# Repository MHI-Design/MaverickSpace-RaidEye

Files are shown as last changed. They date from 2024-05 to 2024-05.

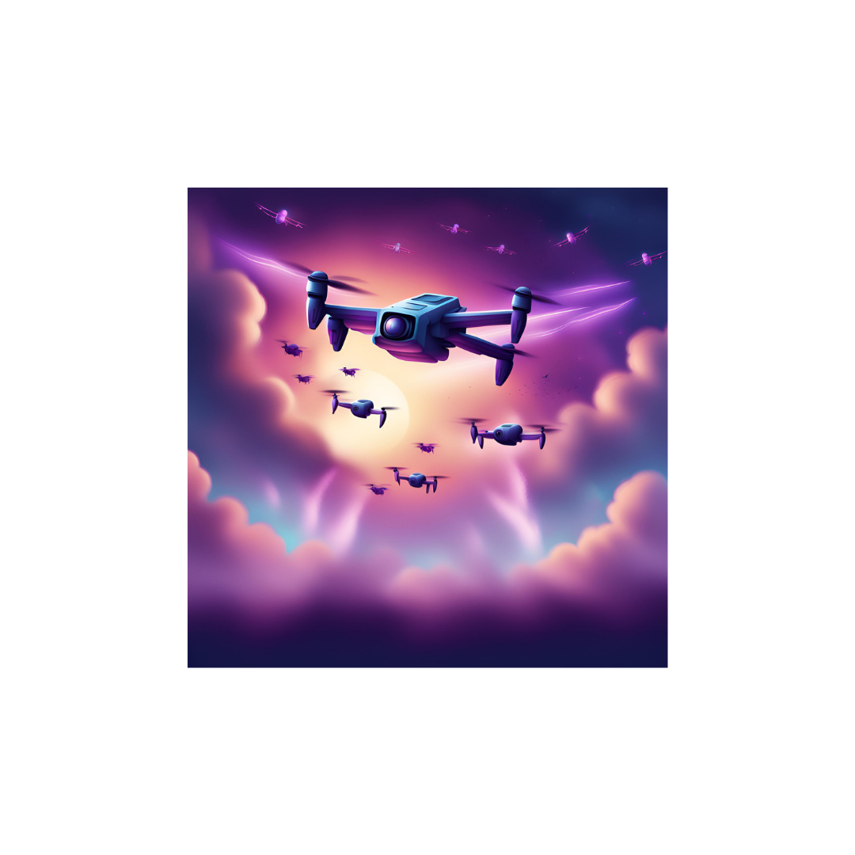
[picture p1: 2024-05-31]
Mobil Uygulama Yazılımı/uygulama/assets/images/Adsız tasarım.png

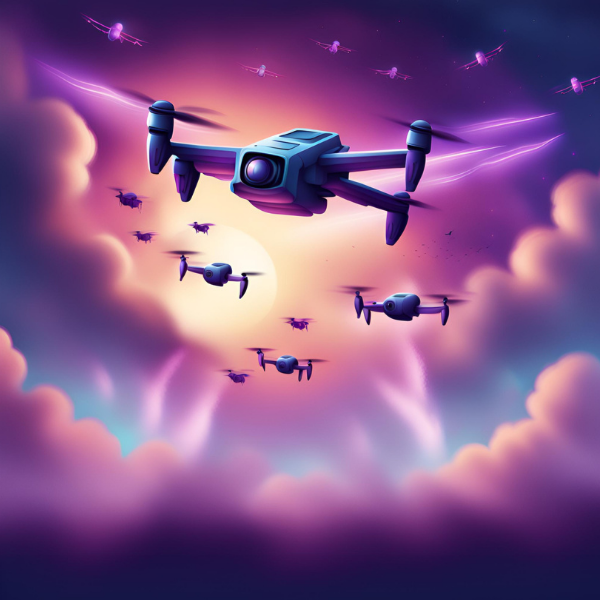
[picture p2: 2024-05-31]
Mobil Uygulama Yazılımı/uygulama/assets/images/drone.png

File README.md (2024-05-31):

# Raid Eye - Kamikaze İHA Sinyal Tespit ve İkaz Sistemi

## Proje Tanıtımı
Raid Eye projesi, askerlerimizin güvenliğini tehdit eden kamikaze insansız hava araçlarına (İHA) karşı önlem almak için geliştirilmiştir. Projenin temel amacı şu şekilde özetlenebilir:

Kamikaze İHA'ların 5.8 GHz frekansındaki kontrol ve görüntü aktarım sinyallerini tespit etmek
Bu sinyallerin kuvvetini ölçerek yaklaşan tehlikeyi belirlemek
Tespit edilen tehlikeyi sesli uyarı sistemiyle askerlerimize bildirerek önlem alınmasını sağlamak
Böylece, FPV (First Person View) teknolojisi kullanan kamikaze İHA'ların neden olabileceği kayıpların önüne geçilmesi hedeflenmektedir. Maverick Space ekibi, askeri operasyonlarda
bilinmeyen alanlarda karşılaşılabilecek bu tehdidin önlenmesi için Raid Eye projesini geliştirmiştir.

Kısaca, Raid Eye sistemi, 5.8 GHz frekansındaki sinyalleri algılayarak yaklaşan kamikaze İHA'lara karşı askerlerimizi önceden uyaran bir güvenlik çözümüdür.

Donanım Tasarım Görselleri
3d_2

https://github.com/MHI-Embedded-Dev/MaverickSpace-RaidEye/assets/132624287/f9e3f8c7-b252-42bd-ad0d-98eca6fa7957

animasyon_gorsel2

Sistem blok şeması
Başlıksız Diyagram drawio

Gömülü yazılımın çalıtığını proteus ile simüle edilmiştir.

simülasyon_jpg

## Dosya Yapısı
- **Donanım Tasarım/**: PCB tasarım dosyaları, montaj animasyon videosu ve 3D kutu tasarımı.
- **Gömülü Yazılımı/**: Gömülü yazılım kaynak kodları ve dokümantasyonu.
- **Mobil Uygulama Yazılımı/**: Arayüz yazılımı kaynak kodları ve dokümantasyonu.
- **Rapor ve Sunum/**: Proje raporları ve sunumları.

## Kurulum ve Çalıştırma
### Donanım
- PCB dosyalarını `Donanım Tasarımı\hecatlon_raid_eye\gerber_to_order` klasöründen indirin ve bir PCB üreticisine gönderin.
-Raid Eye kartının dizgisi için gerekli olan dosyaları ‘Donanım Tasarımı\hecatlon_raid_eye\bom’ malzemeler sipariş verilerek dizgi işlemi yapılabilir.
- Montaj talimatlarına `Donanım Tasarımı\hecatlon_raid_eye\bom` dosyasından ulaşabilirsiniz. Dizgi işleminde süreci hızlandırma bir eklenti ile hazırlanmıştır.



### Gömülü Yazılım
- Gömülü yazılım kaynak kodlarını iki kısıma ayrılmaktadır. ESP32 ve STM32 tarafı olmak üzere STM32 kodları `Gömülü Yazılımı\STM32F446RE\Hecaton_Raid_EYE\Core\Src\main.c` algoritma işleyişi ve sensörleri okuma işlemini yapar. klasöründen bulun.
-ESP32 kodları ‘Gömülü Yazılımı\ESP32-WROOM\Raid_Eye_ESP32’ bluetooth ile mobil uygulamaya bağlantısı gerçekleştirilir. Yapılan sinyal ölçümleri ve ikaz durumu mobil uygulamaya iletilmektedir.
- Yazılımın nasıl yükleneceği ve çalıştırılacağı ile ilgili bilgi için 
ESP32 kodu ve çalıştırma readme dosyası`C:\Github\MaverickSpace-RaidEye\Gömülü Yazılımı\ESP32-WROOM\Raid_Eye_ESP32\readme.txt` dosyasına bakın.
STM32  kodu ve çalıştırma readme dosyası` Gömülü Yazılımı\STM32F446RE\Hecaton_Raid_EYE` dosyasına bakın.

### Arayüz Yazılımı
- Arayüz yazılımı kaynak kodlarını ` Mobil Uygulama Yazılımı\uygulama\src\main.c` klasöründen bulun.
- Mobil Uygulama kodu ve çalıştırma readme dosyası ‘Mobil Uygulama Yazılımı\uygulama\README.txt’ dosyasına bakın.

## İletişim
Muhammed Hüseyin İSMAİL -> mhi.hsynn@gmail.com

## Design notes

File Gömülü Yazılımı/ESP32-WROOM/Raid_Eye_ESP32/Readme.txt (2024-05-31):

//SD CARD
SPI.h
SD.h

//BLUETOOTH BLE
BLEDevice.h
BLEServer.h
BLEUtils.h
BLE2902.h

//I2C
Wire.h

Bu kütühaneleri indirilmesi gereklidir.

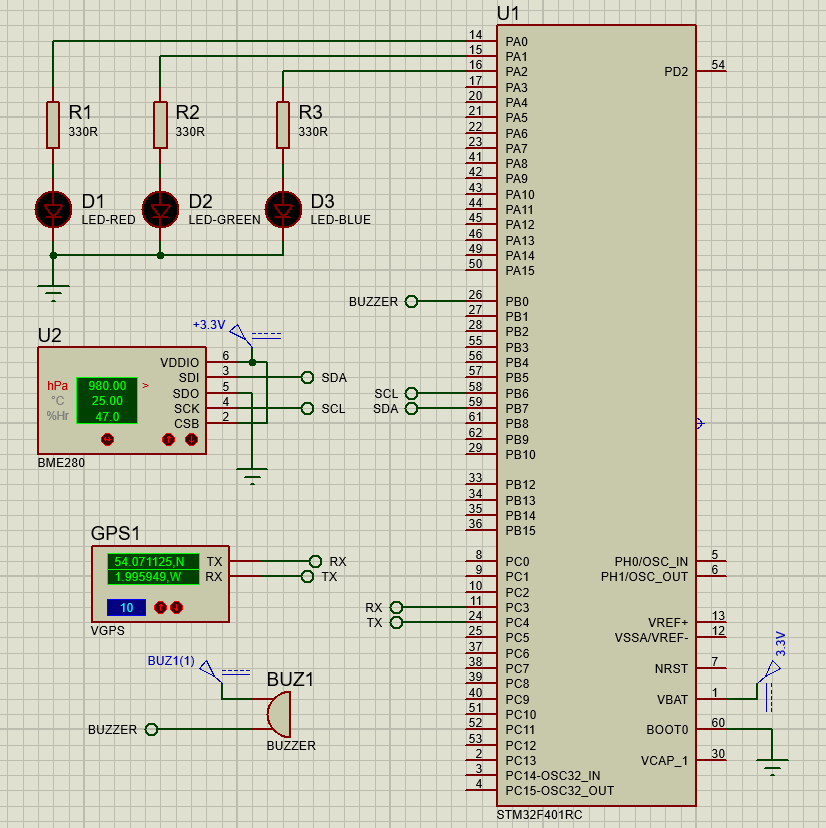
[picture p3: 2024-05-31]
Gömülü Yazılımı/Simülasyon/simülasyon_jpg.png

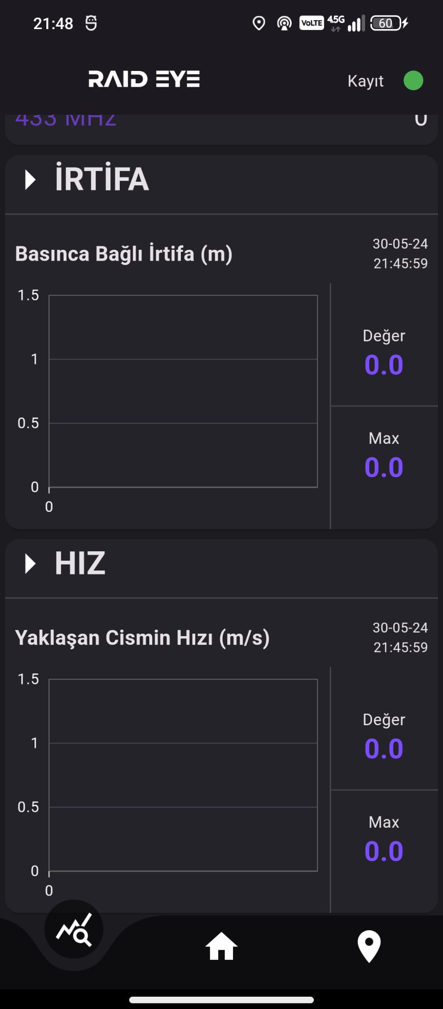
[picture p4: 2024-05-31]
Mobil Uygulama Yazılımı/veri_sayfasi.jpg

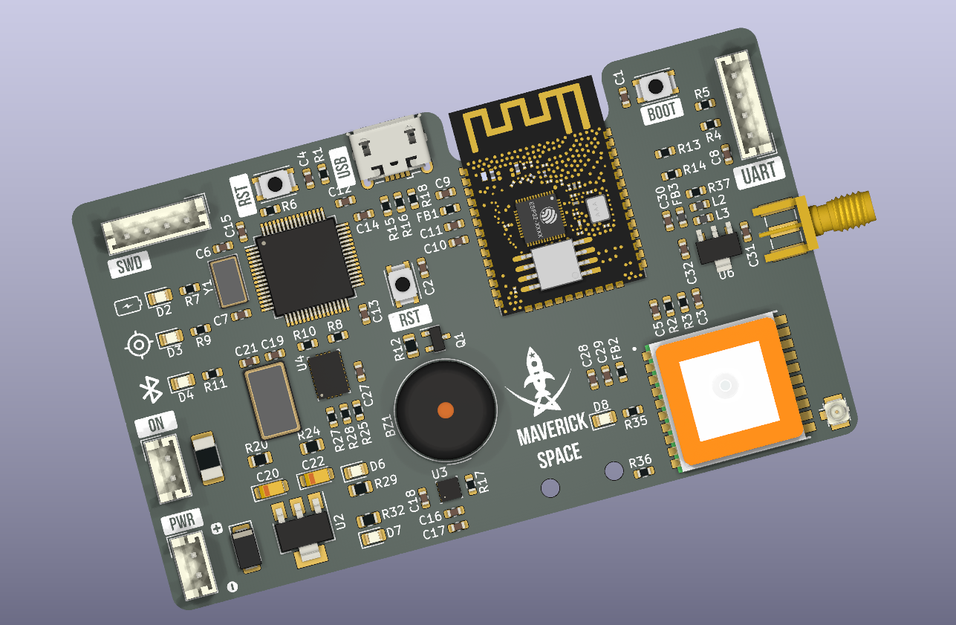
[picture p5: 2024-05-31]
Donanım Tasarımı/3d_2.png

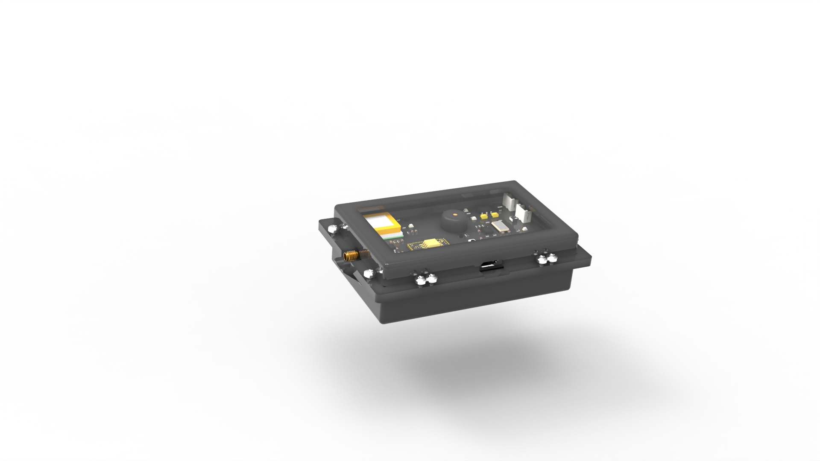
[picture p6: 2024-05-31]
Donanım Tasarımı/animasyon_gorsel2.jpg

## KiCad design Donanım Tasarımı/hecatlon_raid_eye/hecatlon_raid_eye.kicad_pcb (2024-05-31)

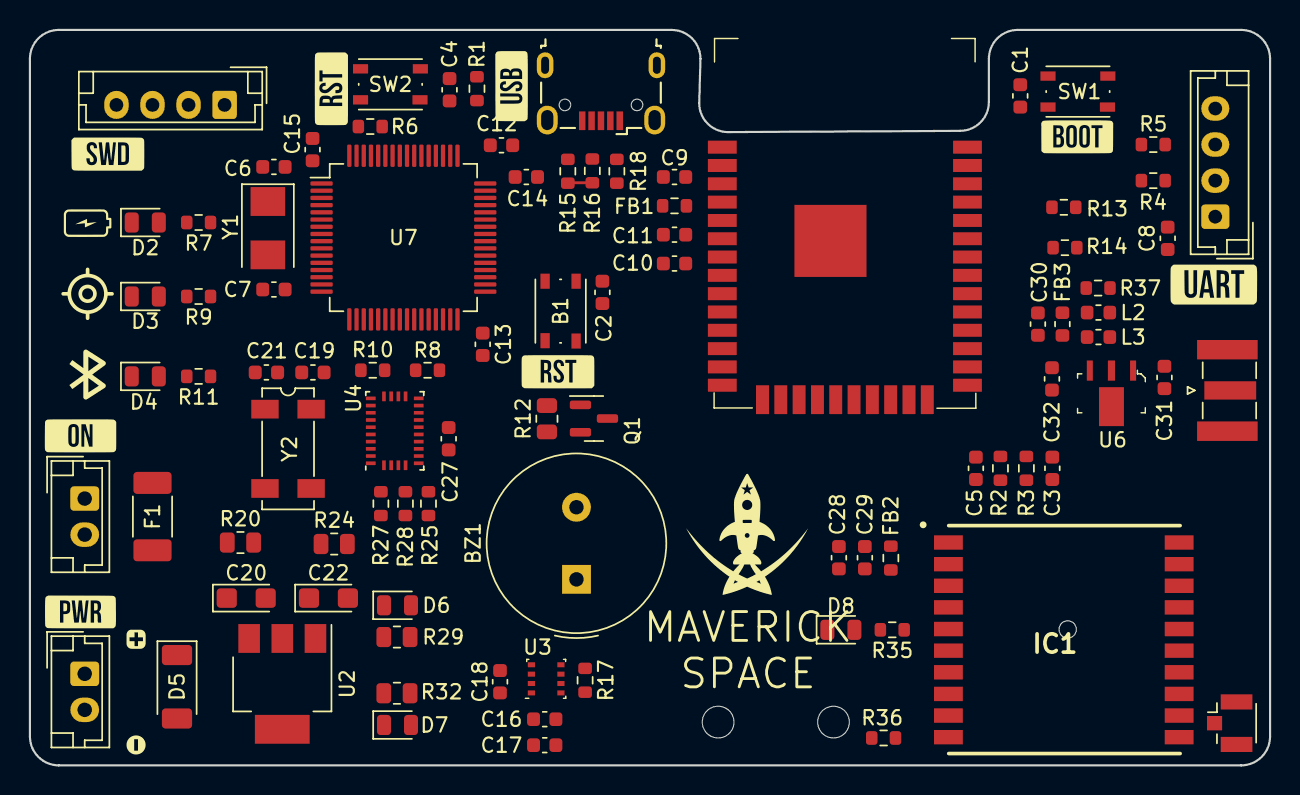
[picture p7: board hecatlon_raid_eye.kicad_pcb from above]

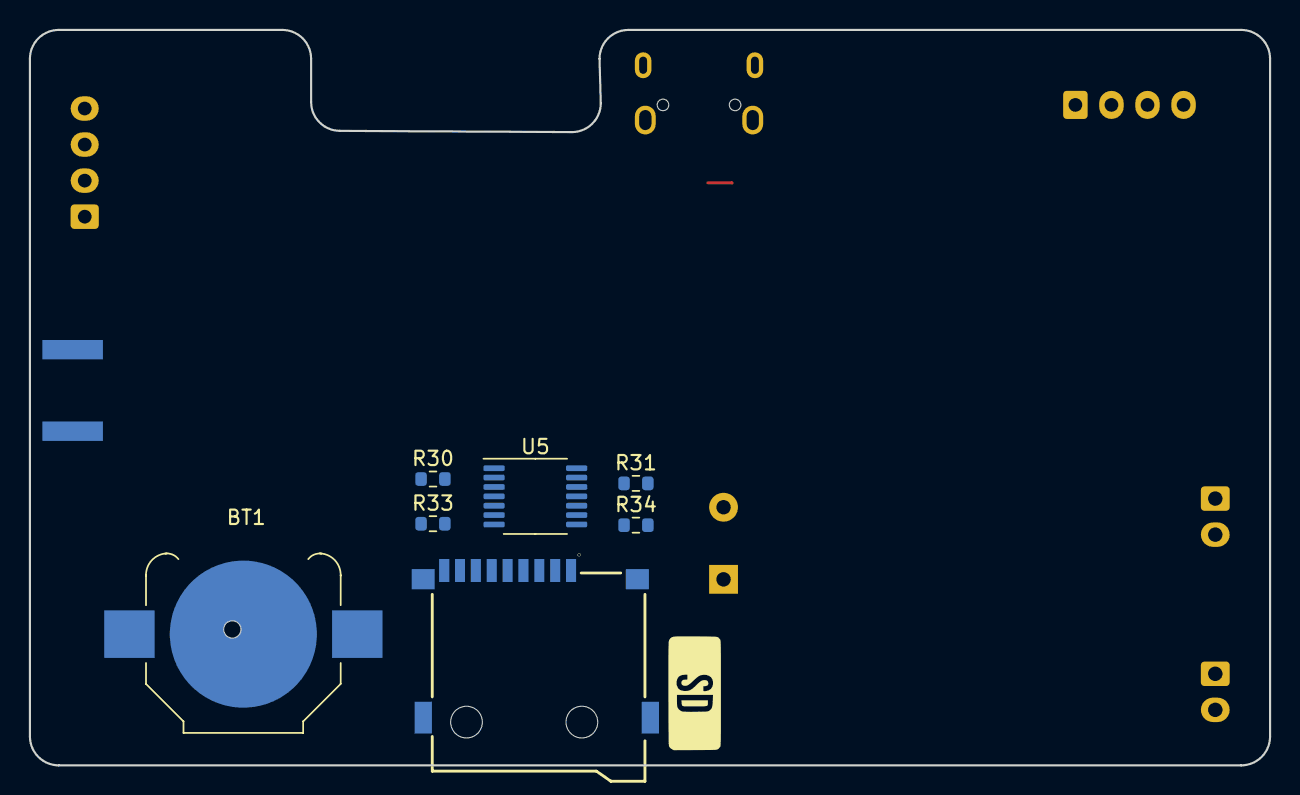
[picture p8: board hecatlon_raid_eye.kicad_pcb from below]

Board: 4 copper layers, 86.0 x 51.0 mm, 97 parts (7 on the bottom side), 76 nets.

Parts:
AE1: Antenna_Shield; U.FL_Hirose_U.FL-R-SMT-1_Vertical
AE2: Antenna_Shield; SMA_Samtec_SMA-J-P-X-ST-EM1_EdgeMount
B1: RESET; SW_Push_1P1T_NO_Vertical_Wuerth_434133025816
BT1: CR1220; BatteryHolder_Keystone_3000_1x12mm
BZ1: Buzzer; Buzzer_TDK_PS1240P02BT_D12.2mm_H6.5mm
C1, C3, C4, C9, C11: 100nF; C_0603_1608Metric
C2, C12, C13, C14, C15, C16, C18, C27, C29: 100n; C_0603_1608Metric
C5: 1nF; C_0603_1608Metric
C6, C7: 10p; C_0603_1608Metric
C8, C10: 10uF; C_0603_1608Metric
C17, C28: 2.2uF; C_0603_1608Metric
C19, C21: 22p; C_0603_1608Metric
C20, C22: 10uF; CP_EIA-3216-18_Kemet-A
C30, C31, C32: 47nF; C_0603_1608Metric
D2, D7, D8: RED; LED_0805_2012Metric
D3: BLUE; LED_0805_2012Metric
D4, D6: GREEN; LED_0805_2012Metric
D5: 1N4007; D_SOD-128
F1: 1A; Fuse_2010_5025Metric_Pad1.52x2.65mm_HandSolder
FB1, FB2: 100R; R_0603_1608Metric
FB3: 1600R; L_0603_1608Metric
IC1: FGPMMOPA6H
J1, J2: SWD; JST_EH_B4B-EH-A_1x04_P2.50mm_Vertical
J3: Anahtar; JST_EH_B2B-EH-A_1x02_P2.50mm_Vertical
J5: USB_B_Mini; USB_Micro-B_Wuerth_629105150521
J6: Power; JST_EH_B2B-EH-A_1x02_P2.50mm_Vertical
J10: Micro_SD_Card; L-KLS1-TF-003-H1.85-R
L2: 110nH; L_0603_1608Metric
L3: 33nH; L_0603_1608Metric
MOD1: ESP32-WROOM-32; ESP32-WROOM-32D
Q1: BC817; SOT-23
R1, R6, R8, R10, R17, R25, R27, R28: 10k; R_0603_1608Metric
R2: 26R; R_0603_1608Metric
R3: 0.8R; R_0603_1608Metric
R4, R5: 0R; R_0603_1608Metric
R7, R9, R11, R35: 470R; R_0603_1608Metric
R12: 470R; R_0805_2012Metric
R13, R14: 2.2k; R_0603_1608Metric
R15: 1.5k; R_0603_1608Metric
R16, R18: 1R; R_0603_1608Metric
R20: 680k; R_0805_2012Metric
R24: 100k; R_0805_2012Metric
R29: 1K; R_0805_2012Metric
R30, R31, R33, R34: 3.3K; R_0603_1608Metric
R32: 10K; R_0805_2012Metric
R36: 10K; R_0603_1608Metric
R37: OPS; R_0603_1608Metric
SW1: BOOT; SW_Push_1P1T_NO_Vertical_Wuerth_434133025816
SW2: RESET; SW_Push_1P1T_NO_Vertical_Wuerth_434133025816
U2: AMS1117-3.3; SOT-223-3_TabPin2
U3: BME280; Bosch_LGA-8_2.5x2.5mm_P0.65mm_ClockwisePinNumbering
U4: BNO055; LGA-28_5.2x3.8mm_P0.5mm
U5: 74LVC125A; TSSOP-14_4.4x5mm_P0.65mm
U6: SKY65017-70LF; TO-243AA
U7: STM32F446RETx; LQFP-64_10x10mm_P0.5mm
Y1: 8MHz; Crystal_SMD_5032-2Pin_5.0x3.2mm
Y2: 32.768Khz; Crystal_SMD_SeikoEpson_MC306-4Pin_8.0x3.2mm

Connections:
+3.3V: C8.2, C10.2, C11.1, C12.1, C13.1, C14.1, C15.1, C16.2, C17.1, C18.1, C22.1, C28.1, C29.1, C30.2, FB1.1, FB2.2, FB3.1, J1.1, J2.1, J10.4 (VDD), R1.1, R8.1, R10.1, R13.1, R14.1, R15.1, R29.1, R36.2, U2.2 (VO), U3.2 (CSB), U3.6 (VDDIO), U3.8 (VDD), U4.3 (VDD), U4.4 (~BOOT_LOAD_PIN), U4.28 (VDDIO), U5.14 (VCC), U7.1 (VBAT), U7.13 (VDDA), U7.19 (VDD), U7.32 (VDD), U7.48 (VDD), U7.64 (VDD)
/CS_LLS: J10.2 (DAT3/CD), U5.8 (3Y)
/DI_LLS: J10.3 (CMD), U5.3 (1Y)
/DO_LLS: J10.7 (DAT0), R31.2
/EN: C4.1, MOD1.3 (EN), R1.2, SW2.2
/GPS_FIX: IC1.5 (3D-FIX), R35.1
/IO_0: C1.1, MOD1.25 (IO0), SW1.2
/SCK_LLS: J10.5 (CLK), U5.6 (2Y)
/UART_RXD0: J1.2, R4.2
/UART_TXD0: J1.3, R5.2
BAT_LEVEL: MOD1.14 (IO12), R20.2, R24.1
BNO_INT: U4.14 (INT), U7.57 (PB5)
BNO_RST: U4.11 (~RESET), U7.56 (PB4)
BOOT0: R6.2, U7.60 (BOOT0)
BUZZER: MOD1.7 (IO35), R12.1
CS: MOD1.29 (IO5), R34.2
GND: AE1.2 (Shield), AE2.2 (Shield), B1.2 (K), BT1.2 (-), C1.2, C2.2, C4.2, C5.1, C6.2, C7.2, C8.1, C9.2, C10.1, C11.2, C12.2, C13.2, C14.2, C15.2, C16.1, C17.2, C18.2, C19.2, C20.2, C21.2, C22.2, C27.2, C28.2, C29.2, C30.1, D2.1 (K), D3.1 (K), D4.1 (K), D6.1 (K), D7.1 (K), D8.1 (K), IC1.3 (GND_1), IC1.8 (GND_2), IC1.12 (GND_3), IC1.19 (GND_4), J1.4, J2.4, J5.4 (ID), J5.5 (GND), J5.6 (Shield), J6.2, J10.6 (VSS), J10.9 (SHIELD), MOD1.1 (GND), MOD1.15 (GND), MOD1.38 (GND), MOD1.39 (GND), Q1.2 (E), R3.1, R6.1, R17.2, R24.2, R25.1, R27.1, R28.2, SW1.1, SW2.1, U2.1 (GND), U3.1 (GND), U3.7 (GND), U4.2 (GND), U4.10 (BL_IND), U4.15 (GNDIO), U4.16 (GNDIO), U4.18 (COM2), U4.25 (GNDIO), U5.1 (1OE), U5.4 (2OE), U5.7 (GND), U5.10 (3OE), U5.13 (4OE), U6.2 (GND), U6.4 (GND), U7.12 (VSSA), U7.18 (VSS), U7.31 (VSS), U7.47 (VSS), U7.63 (VSS), Y2.2, Y2.3
GPS_PPS: IC1.13 (1PPS), U7.41 (PA8)
GPS_RX: IC1.9 (TX), U7.43 (PA10)
GPS_TX: IC1.10 (RX), R36.1, U7.42 (PA9)
GPS_VBACKUP: BT1.1 (+), IC1.4 (VBACKUP)
I2C1_SCL: MOD1.36 (IO22), R13.2, U7.58 (PB6)
I2C1_SDA: MOD1.33 (IO21), R14.2, U7.59 (PB7)
I2C2_SCL: R8.2, U3.4 (SCK), U4.19 (COM1), U7.29 (PB10)
I2C2_SDA: R10.2, U3.3 (SDI), U4.20 (COM0), U7.53 (PC12)
LED1: R7.1, U7.14 (PA0)
LED2: R9.1, U7.15 (PA1)
LED3: R11.1, U7.16 (PA2)
MISO: MOD1.31 (IO19), U5.11 (4Y)
MOSI: MOD1.37 (IO23), R30.1
NRST: B1.1 (2), C2.1, U7.7 (NRST)
unnamed: AE1.1 (A), IC1.11 (EX_ANT)
unnamed: AE2.1 (A), C31.1
unnamed: BZ1.2 (+), Q1.3 (C)
unnamed: C3.2, R2.1, R3.2
unnamed: D2.2 (A), R7.2
unnamed: D3.2 (A), R9.2
unnamed: D4.2 (A), R11.2
unnamed: D5.2 (A), J6.1
unnamed: D5.1 (K), J3.2
unnamed: D6.2 (A), R29.2
unnamed: D7.2 (A), R32.2
unnamed: D8.2 (A), R35.2
unnamed: FB3.2, L2.1, R37.1
unnamed: FB2.1, IC1.1 (VCC)
unnamed: F1.2, J3.1
unnamed: J5.3 (D+), R16.1
unnamed: J5.2 (D-), R18.1
unnamed: L2.2, L3.1, R37.2
unnamed: C9.1, FB1.2, MOD1.2 (3V3)
unnamed: MOD1.34 (RXD0), R5.1
unnamed: MOD1.35 (TXD0), R4.1
unnamed: Q1.1 (B), R12.2
unnamed: R17.1, U3.5 (SDO)
unnamed: C27.1, U4.9 (CAP)
unnamed: R28.1, U4.17 (COM3)
unnamed: R25.2, U4.6 (PS0)
unnamed: R27.2, U4.5 (PS1)
unnamed: C21.1, U4.27 (XIN32), Y2.1
unnamed: C19.1, U4.26 (XOUT32), Y2.4
unnamed: R30.2, U5.2 (1A)
unnamed: R33.2, U5.5 (2A)
unnamed: R34.1, U5.9 (3A)
unnamed: R31.1, U5.12 (4A)
unnamed: C31.2, U6.1 (IN)
unnamed: C32.1, L3.2, U6.3 (OUT)
OSC_IN: C6.1, U7.5 (PH0), Y1.1
OSC_OUT: C7.1, U7.6 (PH1), Y1.2
SCK: MOD1.30 (IO18), R33.1
SGN_FILTER: C5.2, MOD1.24 (IO2), R2.2
SGN_OUT: C3.1, C32.2
SW_CLK: J2.2, U7.49 (PA14)
SW_DIO: J2.3, U7.46 (PA13)
USB+: R15.2, R16.2, U7.45 (PA12)
USB-: R18.2, U7.44 (PA11)
VDD: BZ1.1 (-), C20.1, F1.1, R20.1, R32.1, U2.3 (VI)

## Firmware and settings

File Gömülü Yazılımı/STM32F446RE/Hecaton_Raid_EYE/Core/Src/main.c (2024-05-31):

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
/* Includes ------------------------------------------------------------------*/
#include "main.h"
#include "usb_host.h"

/* USER CODE BEGIN Includes */

//USB
#include "usb_host.h"
#include "usbh_core.h"
#include "usbh_cdc.h" // RTL-SDR cihazı için uygun kütüphane seçilmelidir
#include "string.h"

//BNO055
#include "bno055_stm32.h"

//BME280
#include "BME280_STM32.h"

//GPS
#include "lwgps/lwgps.h"

//GENEL LİB
#include "stdint.h"
#include "stdio.h"
#include "stdbool.h"
#include "math.h"

/* USER CODE END Includes */

/* USER CODE BEGIN PD */

//I2C STM TO ESP
#define I2C_SLAVE_ADDRESS 0x30
#define BUFFER_SIZE 20

//USB
#define BUFFER_SIZE_USB 512 // Veri almak için kullanılacak veri tamponunun boyutu

#define MEDIAN_FILTER_SIZE 5




/* USER CODE END PD */

I2C_HandleTypeDef hi2c1;
I2C_HandleTypeDef hi2c2;

TIM_HandleTypeDef htim1;
TIM_HandleTypeDef htim2;
TIM_HandleTypeDef htim4;
TIM_HandleTypeDef htim6;
TIM_HandleTypeDef htim7;
TIM_HandleTypeDef htim8;

UART_HandleTypeDef huart1;
UART_HandleTypeDef huart3;
DMA_HandleTypeDef hdma_usart1_rx;

/* USER CODE BEGIN PV */

// BNO055 Sensörü
bno055_vector_t bno; // BNO055 vektör verisi
float Heading;        // x ekseninde yön
float Roll;           // y ekseninde eğim
float Pitch;          // z ekseninde eğim

// GPS Verileri
float enlem;   // Enlem verisi
float boylam;  // Boylam verisi

// BME Sensörü
float Pressure;     // Basınç
float Temperature;  // Sıcaklık
float Humidity;     // Nem
float irtifa;       // İrtifa

// Medyan Filtresi
float filter_irtifa; // Medyan irtifa değeri

// GPS
lwgps_t gps;                  // GPS nesnesi
uint8_t rx_buffer[128];       // GPS verilerini depolamak için tampon
bool gps_conn = false;        // GPS bağlantı durumu

// I2C Veri Transferi (STM32 - ESP)
uint8_t i2c_buffer[BUFFER_SIZE]; // I2C veri tamponu

// USB
USBH_HandleTypeDef hUSBHost;    // USB ana bilgisayar arabirimi
uint8_t usb_buffer[BUFFER_SIZE_USB]; // Veriyi depolamak için bir tampon
size_t length;                   // USB veri uzunluğu
USBH_StatusTypeDef status;       // USB durum
int8_t onceki_rssi;              // Önceki RSSI değeri
int8_t rssi_sayac;               // RSSI sayacı


/* USER CODE END PV */

void SystemClock_Config(void);
static void MX_GPIO_Init(void);
static void MX_DMA_Init(void);
static void MX_I2C1_Init(void);
static void MX_I2C2_Init(void);
static void MX_TIM1_Init(void);
static void MX_USART1_UART_Init(void);
static void MX_TIM2_Init(void);
static void MX_TIM4_Init(void);
static void MX_TIM6_Init(void);
static void MX_USART3_UART_Init(void);
static void MX_TIM7_Init(void);
static void MX_TIM8_Init(void);
void MX_USB_HOST_Process(void);

/* USER CODE BEGIN 0 */

// Buffer'daki tüm değerlerin sıfırdan farklı olup olmadığını kontrol eden fonksiyon
bool gps_buffer_kontrol(uint8_t *buffer, size_t length) {
    for (size_t i = 0; i < length; i++) {
        if (buffer[i] == 0) {
            return false;
        }
    }
    return true;
}

// Kullanıcı callback fonksiyonu
void USBH_UserProcess(USBH_HandleTypeDef *phost, uint8_t id) {
    switch (id) {
        case HOST_USER_SELECT_CONFIGURATION:
            break;
        case HOST_USER_DISCONNECTION:
            break;
        case HOST_USER_CLASS_ACTIVE:
            break;
        case HOST_USER_CONNECTION:
            break;
        default:
            printf("Unhandled user process: %d\n", id);
            break;
    }
}

//Basınc irtifa func
float basinc_irtifa_cevir()
{
	BME280_Measure();
	return 44330 * (1.0 - pow((Pressure/100) / Pressure, 0.1903));
}

void HAL_UART_RxCpltCallback(UART_HandleTypeDef *huart)
{
	if(huart == &huart1) {
		lwgps_process(&gps, rx_buffer, 128);
		enlem = gps.latitude;
		boylam = gps.longitude;

		gps_conn = gps_buffer_kontrol(rx_buffer, sizeof(rx_buffer));

	}
}

//Float değeri uint8_t dönüştürür
void floatToBytes(float floatValue, uint8_t byteArray[]) {
    // Float değerini unsigned char dizisine dönüştür
    uint8_t *ptr = (uint8_t*)&floatValue;

    // Her bir byte'ı unsigned char dizisine kopyala
    for (int i = 0; i < sizeof(float); i++) {
        byteArray[i] = *ptr++;
    }
}

//TIMER FUNC
void HAL_TIM_PeriodElapsedCallback(TIM_HandleTypeDef *htim)
{
	//BNO055 OKU
	if (htim->Instance == TIM2)//200Hz
	{
		  bno = bno055_getVectorEuler(); //FÜZYONLU VERİLER

		  Heading = bno.x;
		  Roll = bno.y;
		  Pitch = bno.z;

	}

	//BME280 READ
	if (htim->Instance == TIM4)//100Hz
	{
		irtifa = basinc_irtifa_cevir();
		//uint8_t tipinde değikenlere atama yapılacak
		//uint16_t low vr high bitlere bölünerek gönderilecek
		//float ise virgülden sonraki hanelere göre bitlere bölünerek atanacaltır.
		floatToBytes(irtifa, i2c_buffer);
	}

	//I2C VERI GONDER
	if (htim->Instance == TIM6)//50Hz
	{
		//********************I2C Veri Paketi**********************//
		//		0. byte -> irtifa low değeri
		//		1. byte -> irtifa high değeri
		//		2. byte -> frekans 1. bytesi
		//		3. byte -> frekans 1. bytesi
		//		4. byte -> frekans 1. bytesi
		//		5. byte -> frekans 1. bytesi
		//		6. byte -> frekans 1. bytesi
		//		7. byte -> frekans 1. bytesi
		//		8. byte -> frekans 1. bytesi
		//		9. byte -> rssı değeri (sinyal güç ölçüsü)
		//********************I2C Veri Paketi**********************//

		//I2C ile ESP gönderme işlemi
		if (HAL_I2C_Master_Transmit(&hi2c2, I2C_SLAVE_ADDRESS << 1, i2c_buffer, sizeof(i2c_buffer), HAL_MAX_DELAY) != HAL_OK) {
		    Error_Handler();
		}
	}

	if (htim->Instance == TIM7)//50Hz
	{
		//GPS LED
		if(gps_conn == true)
		{
			HAL_GPIO_WritePin(LED2_GPIO_Port, LED1_Pin, 0);
		}
		if(gps_conn == false)
		{
			HAL_GPIO_TogglePin(LED2_GPIO_Port, LED1_Pin);

		}


	}

	//Algoritma İkaz
	if (htim->Instance == TIM8)//50Hz
	{
		checkRSSI(i2c_buffer, &onceki_rssi, &rssi_sayac);
	}
}


void checkRSSI(uint8_t *i2c_buffer, uint8_t *onceki_rssi, uint8_t *rssi_sayac) {
    if (i2c_buffer[9] > *onceki_rssi) {
        (*rssi_sayac)++;
        if (*rssi_sayac >= 10) {
            i2c_buffer[10] = 1;
        }
    } else {
        *rssi_sayac = 0;
    }

    *onceki_rssi = i2c_buffer[9];
}


void USBH_CDC_ReceiveCallback(USBH_HandleTypeDef *phost)
{
    USBH_Process(&hUSBHost);

    size_t i = 0;
    while (i < length) {
        uint8_t command = usb_buffer[i];

        switch (command) {
            case 0x01:
                if (i + 8 < length) {
                    // Frekans ayarı komutunu işle
                    for (int j = 0; j < 6; j++) {
                        i2c_buffer[j + 2] = usb_buffer[i + j + 1];
                    }
                    i += 8;
                } else {
                    // Yetersiz veri, diziye atanmaz
                }
                break;
            case 0x02:
                if (i + 1 < length) {
                    // RSSI değeri komutunu işle
                    i2c_buffer[9] = usb_buffer[i + 1];
                    i += 1;
                } else {
                    // Yetersiz veri, diziye atanmaz
                }
                break;
            default:
                break;
        }
        i++;
    }
}

/* USER CODE END 0 */

/**
  * @brief  The application entry point.
  * @retval int
  */
int main(void)
{
  /* MCU Configuration--------------------------------------------------------*/

  /* Reset of all peripherals, Initializes the Flash interface and the Systick. */
  HAL_Init();

  /* Configure the system clock */
  SystemClock_Config();

  /* Initialize all configured peripherals */
  MX_GPIO_Init();
  MX_DMA_Init();
  MX_I2C1_Init();
  MX_I2C2_Init();
  MX_TIM1_Init();
  MX_USART1_UART_Init();
  MX_USB_HOST_Init();
  MX_TIM2_Init();
  MX_TIM4_Init();
  MX_TIM6_Init();
  MX_USART3_UART_Init();
  MX_TIM7_Init();
  MX_TIM8_Init();
  /* USER CODE BEGIN 2 */

  //TIMER
  HAL_TIM_Base_Start_IT(&htim2);
  HAL_TIM_Base_Start_IT(&htim4);
  HAL_TIM_Base_Start_IT(&htim6);
  HAL_TIM_Base_Start_IT(&htim7);
  HAL_TIM_Base_Start_IT(&htim8);

  //USB
  MX_USB_HOST_Init();
  status = USBH_Init(&hUSBHost, USBH_UserProcess, 0);
  USBH_CDC_ReceiveCallback(&hUSBHost);

  //BME280
  BME280_Config(OSRS_2, OSRS_16, OSRS_1, MODE_NORMAL, T_SB_0p5, IIR_16);

  BME280_Measure();
  HAL_Delay(50);
  Pressure=Pressure/100;

  //BNO055
  bno055_assignI2C(&hi2c1);
  bno055_setup();
  bno055_setOperationModeNDOF();

  //GPS
  lwgps_init(&gps);
  HAL_UART_Receive_DMA(&huart1, (uint8_t *) rx_buffer, 128);

  /* USER CODE END 2 */

  /* Infinite loop */
  /* USER CODE BEGIN WHILE */
  while (1)
  {
    /* USER CODE END WHILE */
    MX_USB_HOST_Process();

    /* USER CODE BEGIN 3 */


  }

  /* USER CODE END 3 */
}

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


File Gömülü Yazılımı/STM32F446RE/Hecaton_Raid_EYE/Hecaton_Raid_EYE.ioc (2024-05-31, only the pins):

Mcu.UserName=STM32F446RETx
PA0-WKUP.GPIO_Label=LED1
PA0-WKUP.Signal=GPIO_Output
PA1.GPIO_Label=LED2
PA1.Signal=GPIO_Output
PA10.GPIO_Label=GPS_RX1
PA10.Signal=USART1_RX
PA11.Signal=USB_OTG_FS_DM
PA12.Signal=USB_OTG_FS_DP
PA13.Signal=SYS_JTMS-SWDIO
PA14.Signal=SYS_JTCK-SWCLK
PA2.GPIO_Label=LED3
PA2.Signal=GPIO_Output
PA8.GPIO_Label=GPS_PSS
PA8.Signal=S_TIM1_CH1
PA9.GPIO_Label=GPS_TX1
PA9.Signal=USART1_TX
PB10.Signal=I2C2_SCL
PB4.GPIO_Label=BNO_RST
PB4.Signal=GPIO_Output
PB5.GPIO_Label=BNO_INT
PB5.Signal=GPIO_Output
PB6.Signal=I2C1_SCL
PB7.Signal=I2C1_SDA
PC0.GPIO_Label=BUZZER
PC0.Signal=GPIO_Output
PC10.Signal=USART3_TX
PC12.Signal=I2C2_SDA
PC5.Signal=USART3_RX
PH0-OSC_IN.Signal=RCC_OSC_IN
PH1-OSC_OUT.Signal=RCC_OSC_OUT

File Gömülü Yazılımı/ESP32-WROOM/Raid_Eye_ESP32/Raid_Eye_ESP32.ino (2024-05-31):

#include <SPI.h>
#include <SD.h>
#include <BLEDevice.h>
#include <BLEServer.h>
#include <BLEUtils.h>
#include <BLE2902.h>
#include <Wire.h>

#define I2C_SLAVE_ADDRESS 0x30
#define BUFFER_SIZE 10

// Veri alındı bayrağı
volatile bool dataReceived = false;

// I2C veri tamponu
volatile uint8_t buffer[BUFFER_SIZE];
volatile int bufferLength = 0;

// Batarya seviyesi pin tanımı
const int Battery_Level_Pin = 12;

// Doppler sabitleri
const float soundSpeed = 343.0; 
const float sourceFrequency = 2400000.0;

// LED pinleri
const int LED1 = 33; // Batarya Seviyesi
const int LED3 = 32; // BLE
uint8_t ikaz_sayac = 0;

// SD kart pin tanımları
const int chipSelect = 5;
const int writeInterval = 1000; 
unsigned long lastWriteTime = 0;

// Frekans ve diğer değişkenler
long frequency;
float freq_ghz;
float dopplerShift;
float speed;

// BLE bağlantı durumu
bool ble_connected = false;
uint8_t ble_sayac = 0;

// BLE servis ve karakteristik tanımlamaları
BLECharacteristic *pCharacteristic;

// Son BLE gönderim zamanı ve gönderim aralığı
unsigned long lastSendTime = 0;
const unsigned long sendInterval = 200; 

// BLE bağlantı durumu için geri arama sınıfı
class MyServerCallbacks : public BLEServerCallbacks {
    void onConnect(BLEServer* pServer) {
      ble_connected = true;
    };
    void onDisconnect(BLEServer* pServer) {
      ble_connected = false;
    };
};

void setup() {
  Serial.begin(115200);

  pinMode(LED1, OUTPUT);
  pinMode(LED3, OUTPUT);
  pinMode(Battery_Level_Pin, INPUT);

  Wire.begin(I2C_SLAVE_ADDRESS);
  Wire.onReceive(receiveEvent);

  if (!SD.begin(chipSelect)) {
    Serial.println("Kart başlatılamadı. Karta erişilemiyor!");
    return;
  }

  BLEDevice::init("Raid Eye");
  BLEServer *pServer = BLEDevice::createServer();
  pServer->setCallbacks(new MyServerCallbacks());

  BLEService *pService = pServer->createService(BLEUUID("4fafc201-1fb5-459e-8fcc-c5c9c331914b"));
  pCharacteristic = pService->createCharacteristic(
                      BLEUUID("beb5483e-36e1-4688-b7f5-ea07361b26a8"),
                      BLECharacteristic::PROPERTY_READ |
                      BLECharacteristic::PROPERTY_WRITE |
                      BLECharacteristic::PROPERTY_NOTIFY |
                      BLECharacteristic::PROPERTY_INDICATE
                    );
  pCharacteristic->setValue("RaidEye_BLE");
  pCharacteristic->addDescriptor(new BLE2902());
  pService->start();
  pServer->getAdvertising()->start();
}

void loop() {
  if (dataReceived) {
    processI2CData();
    dataReceived = false; 
  }

  sdCardWriteData();
  checkBLEConnection();
  sendBLEData();
}

void processI2CData() {
  frequency = ((long)buffer[3] << 40) | ((long)buffer[4] << 32) |
              ((long)buffer[5] << 24) | ((long)buffer[6] << 16) |
              ((long)buffer[7] << 8) | buffer[8];

  Serial.printf("Frekans ayarı komutu alındı: %ld Hz\n", frequency);

  freq_ghz = frequency / 1000000.0;

  if (buffer[10] == 1) {
    audibleAlertSystem();
  }

  dopplerShift = frequency - sourceFrequency; 
  speed = calculateSpeed(dopplerShift, sourceFrequency, soundSpeed);
}

void sdCardWriteData() {
  unsigned long currentTime = millis(); 
  if (currentTime - lastWriteTime >= writeInterval) {
    lastWriteTime = currentTime;
    File dataFile = SD.open("raid_eye_data.txt", FILE_WRITE);
    if (dataFile) {
      for (int i = 0; i < BUFFER_SIZE; i++) {
        dataFile.print(buffer[i]);
        dataFile.print('\t');
      }
      dataFile.println();
      dataFile.close();
      Serial.println("Veri yazma işlemi tamamlandı.");
    } else {
      Serial.println("Veri dosyası açılamadı.");
    }
  }
}

void sendBLEData() {
  unsigned long currentTime = millis();
  if (currentTime - lastSendTime >= sendInterval) {
    pCharacteristic->setValue(convertArrayToString(buffer, BUFFER_SIZE));
    pCharacteristic->notify(); 
    lastSendTime = currentTime;
  }
}

String convertArrayToString(const uint8_t *array, size_t length) {
  String str = "";
  for (size_t i = 0; i < length; i++) {
    str += String(array[i]);
    if (i < length - 1) {
      str += ", "; 
    }
  }
  return str;
}

void audibleAlertSystem() {
  digitalWrite(LED1, !digitalRead(LED1));
  delay(50);
  if (ikaz_sayac > 20) {
    ikaz_sayac = 0;
    digitalWrite(LED1, LOW); 
  }
}

void checkBLEConnection() {
  if(ble_connected == true){
    ble_sayac++;
    if(ble_sayac<10){
      digitalWrite(LED3, !digitalRead(LED3));
      delay(5);
    }
    else{
      ble_sayac=0;
      digitalWrite(LED3, HIGH);
    }
  }
}

void receiveEvent(int howMany) {
  bufferLength = 0;
  while (Wire.available()) {
    buffer[bufferLength++] = Wire.read();
  }
  dataReceived = true;
}

float calculateSpeed(float dopplerShift, float sourceFrequency, float soundSpeed) {
  return (dopplerShift * soundSpeed) / (2.0 * sourceFrequency);
}

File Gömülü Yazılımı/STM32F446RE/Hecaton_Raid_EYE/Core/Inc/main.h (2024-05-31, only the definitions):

#define BUZZER_Pin GPIO_PIN_0
#define BUZZER_GPIO_Port GPIOC
#define LED1_Pin GPIO_PIN_0
#define LED1_GPIO_Port GPIOA
#define LED2_Pin GPIO_PIN_1
#define LED2_GPIO_Port GPIOA
#define LED3_Pin GPIO_PIN_2
#define LED3_GPIO_Port GPIOA
#define GPS_PSS_Pin GPIO_PIN_8
#define GPS_PSS_GPIO_Port GPIOA
#define GPS_TX1_Pin GPIO_PIN_9
#define GPS_TX1_GPIO_Port GPIOA
#define GPS_RX1_Pin GPIO_PIN_10
#define GPS_RX1_GPIO_Port GPIOA
#define BNO_RST_Pin GPIO_PIN_4
#define BNO_RST_GPIO_Port GPIOB
#define BNO_INT_Pin GPIO_PIN_5
#define BNO_INT_GPIO_Port GPIOB

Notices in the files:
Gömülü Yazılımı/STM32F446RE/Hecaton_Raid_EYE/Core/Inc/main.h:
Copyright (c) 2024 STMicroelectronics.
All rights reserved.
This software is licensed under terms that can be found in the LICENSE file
